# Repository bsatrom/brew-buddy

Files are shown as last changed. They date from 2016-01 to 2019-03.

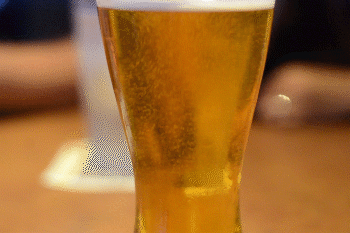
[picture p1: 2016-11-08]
resources/images/bubbles.gif

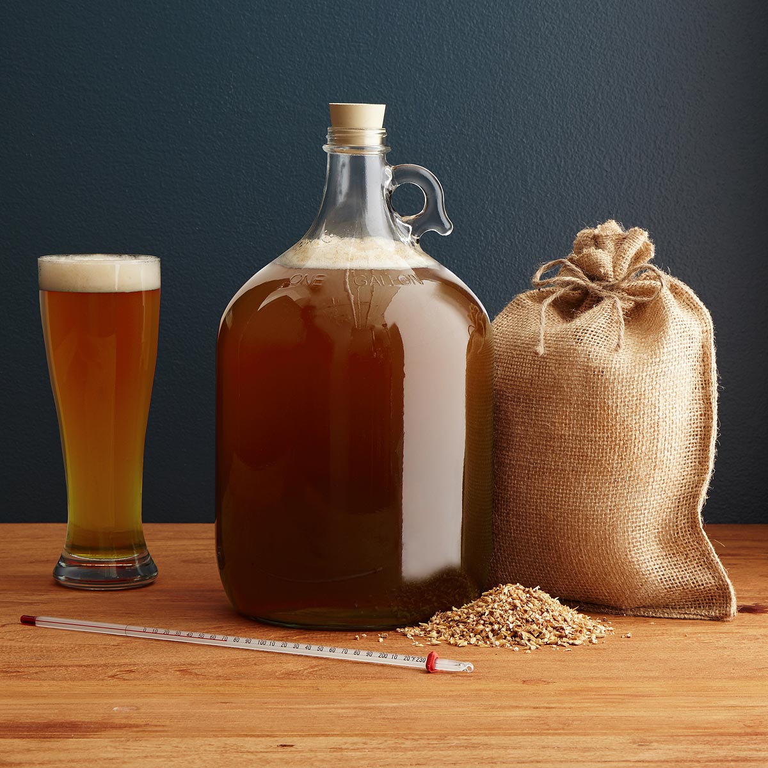
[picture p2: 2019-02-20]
resources/images/homebrew.jpg

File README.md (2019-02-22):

# Brew Buddy

Build Status (https://dev.azure.com/brandon0360/BrewBuddy/_build/latest?definitionId=1&branchName=master)

Source for the BrewBuddy project. Contains sources for board hardware/layout, firmware and a 3d printed enclosure.

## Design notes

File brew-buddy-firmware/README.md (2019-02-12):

# brew-buddy-firmware

A Particle project named brew-buddy-firmware

## Welcome to your project!

Every new Particle project is composed of 3 important elements that you'll see have been created in your project directory for brew-buddy-firmware.

#### ```/src``` folder:  
This is the source folder that contains the firmware files for your project. It should *not* be renamed. 
Anything that is in this folder when you compile your project will be sent to our compile service and compiled into a firmware binary for the Particle device that you have targeted.

If your application contains multiple files, they should all be included in the `src` folder. If your firmware depends on Particle libraries, those dependencies are specified in the `project.properties` file referenced below.

#### ```.ino``` file:
This file is the firmware that will run as the primary application on your Particle device. It contains a `setup()` and `loop()` function, and can be written in Wiring or C/C++. For more information about using the Particle firmware API to create firmware for your Particle device, refer to the [Firmware Reference](https://docs.particle.io/reference/firmware/) section of the Particle documentation.

#### ```project.properties``` file:  
This is the file that specifies the name and version number of the libraries that your project depends on. Dependencies are added automatically to your `project.properties` file when you add a library to a project using the `particle library add` command in the CLI or add a library in the Desktop IDE.

## Adding additional files to your project

#### Projects with multiple sources
If you would like add additional files to your application, they should be added to the `/src` folder. All files in the `/src` folder will be sent to the Particle Cloud to produce a compiled binary.

#### Projects with external libraries
If your project includes a library that has not been registered in the Particle libraries system, you should create a new folder named `/lib/<libraryname>/src` under `/<project dir>` and add the `.h`, `.cpp` & `library.properties` files for your library there. Read the [Firmware Libraries guide](https://docs.particle.io/guide/tools-and-features/libraries/) for more details on how to develop libraries. Note that all contents of the `/lib` folder and subfolders will also be sent to the Cloud for compilation.

## Compiling your project

When you're ready to compile your project, make sure you have the correct Particle device target selected and run `particle compile <platform>` in the CLI or click the Compile button in the Desktop IDE. The following files in your project folder will be sent to the compile service:

- Everything in the `/src` folder, including your `.ino` application file
- The `project.properties` file for your project
- Any libraries stored under `lib/<libraryname>/src`

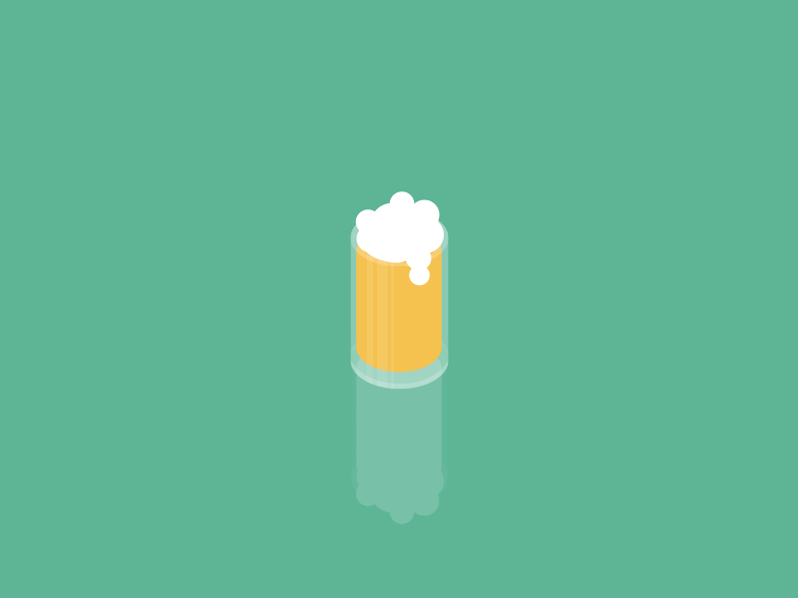
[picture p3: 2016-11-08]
resources/images/animation.gif

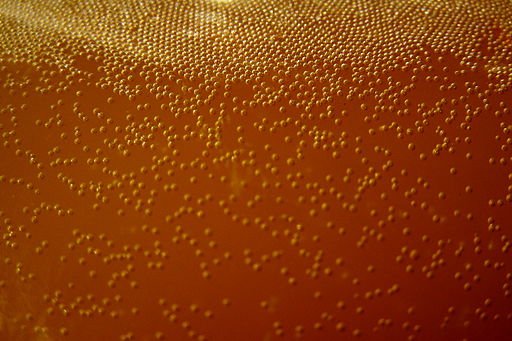
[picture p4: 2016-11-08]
resources/images/bubbles.jpg

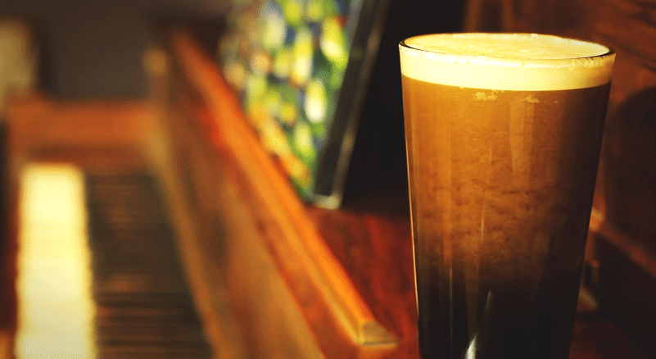
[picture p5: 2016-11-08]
resources/images/goodstuff.gif

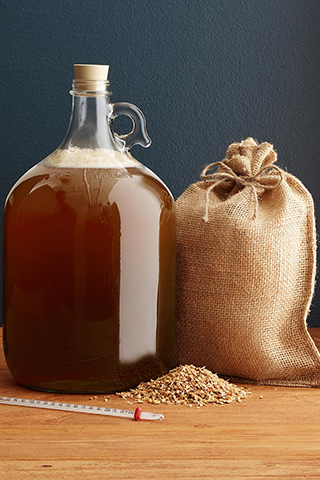
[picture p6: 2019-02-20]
resources/images/brew.bmp

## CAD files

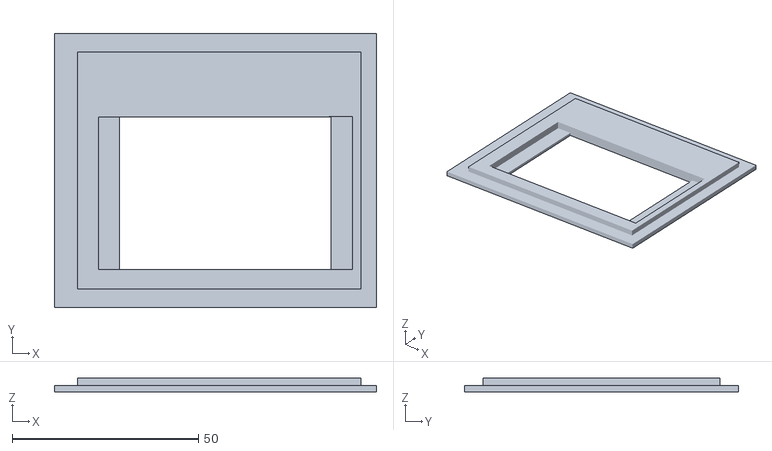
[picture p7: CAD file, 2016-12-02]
brew-buddy-enclosure/enclosure-top.stl
86.5 x 73.5 x 3.72

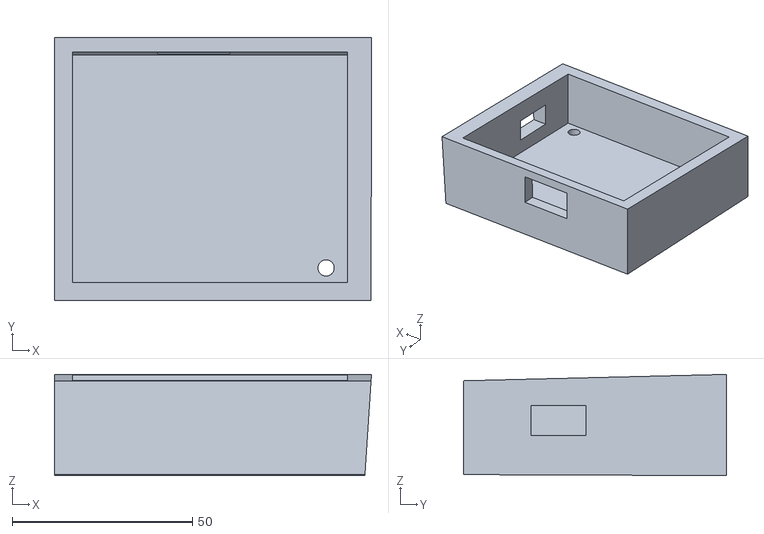
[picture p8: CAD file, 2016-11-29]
brew-buddy-enclosure/enclosure.stl
87.8 x 73.0 x 28.0

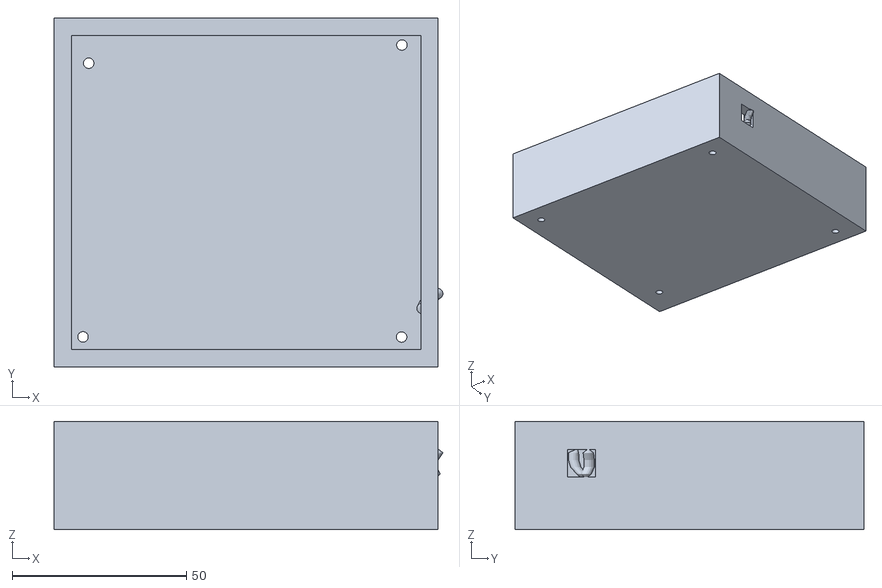
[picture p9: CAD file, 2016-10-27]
brew-buddy-enclosure/enclosure-with-supports.stl
111.5 x 100.0 x 31.0

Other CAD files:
brew-buddy-enclosure/Untitled.stl

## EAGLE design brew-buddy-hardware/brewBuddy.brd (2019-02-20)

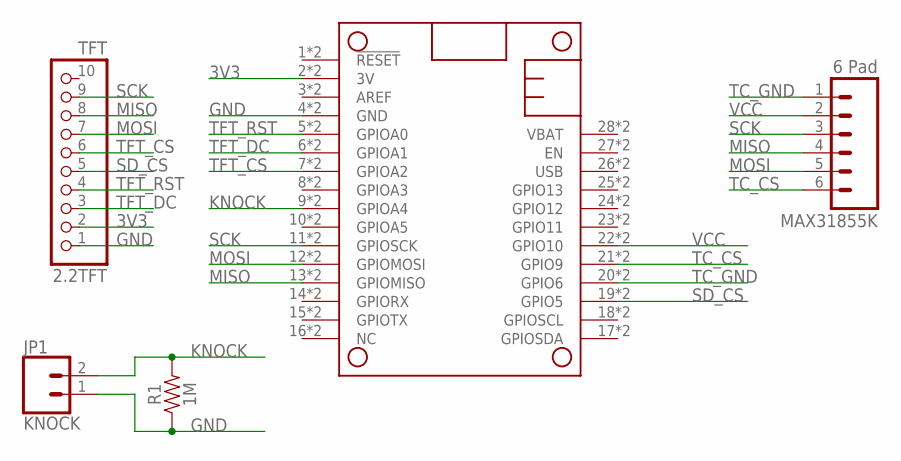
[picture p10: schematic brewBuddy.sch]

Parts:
2.2TFT: TFT; MICROBUILDER_1X10_ROUND_2MM
JP1: KNOCK; SCREWTERMINAL-5MM-2
MAX31855K: 6 Pad; 1X06_LONGPADS
MS1: FEATHERWING_SMTDUAL; FEATHERWING_SMT2
R1: 1M; 0805

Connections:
3V3: 2.2TFT.2, MS1.2 (3V), MS1.2' (3V)
GND: 2.2TFT.1, JP1.1, MS1.4 (GND), MS1.4' (GND), R1.1
KNOCK: JP1.2, MS1.9 (GPIOA4), MS1.9' (GPIOA4), R1.2
MISO: 2.2TFT.8, MAX31855K.4, MS1.13 (GPIOMISO), MS1.13' (GPIOMISO)
MOSI: 2.2TFT.7, MAX31855K.5, MS1.12 (GPIOMOSI), MS1.12' (GPIOMOSI)
SCK: 2.2TFT.9, MAX31855K.3, MS1.11 (GPIOSCK), MS1.11' (GPIOSCK)
SD_CS: 2.2TFT.5, MS1.19 (GPIO5), MS1.19' (GPIO5)
TC_CS: MAX31855K.6, MS1.21 (GPIO9), MS1.21' (GPIO9)
TC_GND: MAX31855K.1, MS1.20 (GPIO6), MS1.20' (GPIO6)
TFT_CS: 2.2TFT.6, MS1.7 (GPIOA2), MS1.7' (GPIOA2)
TFT_DC: 2.2TFT.3, MS1.6 (GPIOA1), MS1.6' (GPIOA1)
TFT_RST: 2.2TFT.4, MS1.5 (GPIOA0), MS1.5' (GPIOA0)
VCC: MAX31855K.2, MS1.22 (GPIO10), MS1.22' (GPIO10)

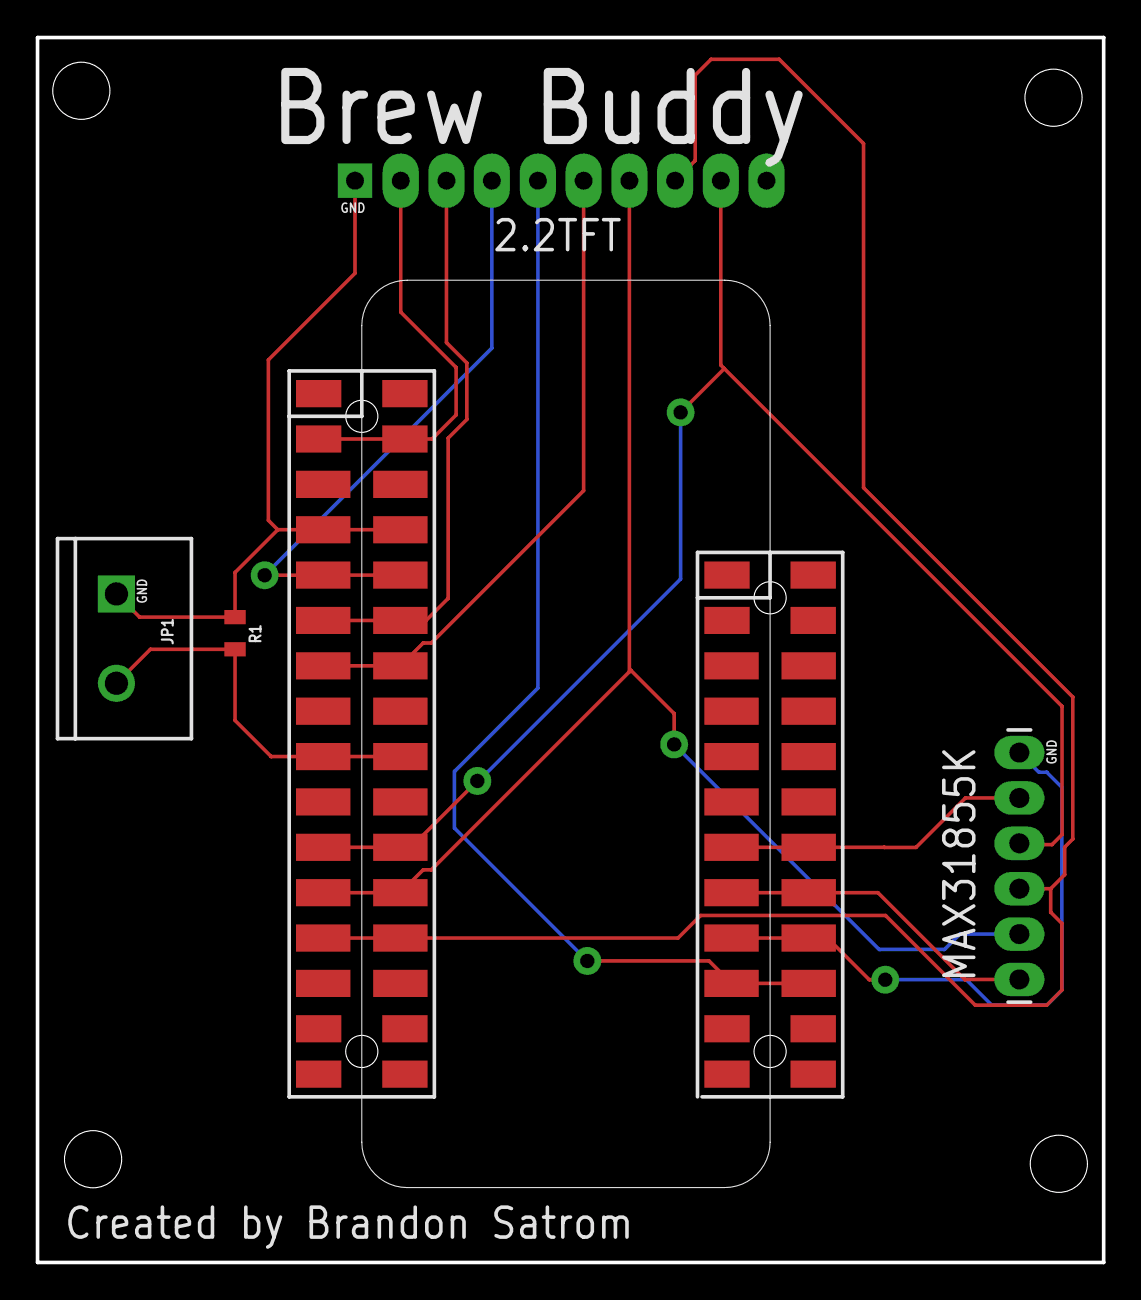
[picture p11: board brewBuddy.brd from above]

Board: 2 copper layers, 59.7 x 68.6 mm, 5 parts (0 on the bottom side), 13 nets.

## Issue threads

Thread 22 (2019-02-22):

Fix temp monitoring posts to Device Cloud

bsatrom, 2019-02-22:

Closed 2019-02-28.

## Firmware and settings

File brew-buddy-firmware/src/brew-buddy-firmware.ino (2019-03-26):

#include "math.h"
#include "QueueArray.h"
#include "beerBitmap.h"

// Thermocouple Includes
#include "SparkFunMAX31855k.h"

// TFT Includes
#include "Adafruit_ILI9341.h"
#include "Adafruit_ImageReader.h"

// Include for SD Card reader on TFT
#include "SdFat.h"

// Include MQTT Library to enable the Azure IoT Hub to call back to our device
#include "MQTT-TLS.h"
#include "certs/certs.h"

// Json parser for working with MQTT responses from Azure IoT Hub
#include "JsonParserGeneratorRK.h"
JsonParserStatic<2048, 100> jsonParser;

// App Version Constant
#define APP_VERSION "v1.0"

SYSTEM_THREAD(ENABLED);

String deviceID;

// Thermocouple Variables
const uint8_t CHIP_SELECT_PIN = D4;
// SCK, MISO & MOSI are defined on Particle 3rd Gen HW at A6-A8
const uint8_t VCC = D5;
const uint8_t GND = D3;
// Instantiate an instance of the SparkFunMAX31855k class
SparkFunMAX31855k probe(CHIP_SELECT_PIN, VCC, GND);

// CS Pin for SD Card on TFT
#define SD_CS D2
#define TFT_CS A2
#define TFT_DC A1
#define TFT_RST A0
// Use hardware SPI
// cs = A2, dc = A1, rst = A0
Adafruit_ILI9341 tft = Adafruit_ILI9341(TFT_CS, TFT_DC, TFT_RST);
Adafruit_ImageReader reader; // Class w/image-reading functions
Adafruit_Image img;          // An image loaded into RAM
int32_t width = 0,           // BMP image dimensions
    height = 0;

#define TFT_SPEED 120000000
#define BATT_LOW_VOLTAGE 30

// SD Card
SdFat sd;

// #include "bmpDraw.h"

// Knock sensor pin
const uint8_t KNOCK_PIN = A4;

// Timing Variables
unsigned long previousTempMillis = 0;
unsigned long tempInterval = 5000;
unsigned long startTime = 0;
unsigned long elapsedTime;
float previousTemp = 0;

// Timing variables for posting readings to the cloud
unsigned long postInterval = 120000;
unsigned long previousPostMillis = 0;

// Timing variables for checking the battery state
unsigned long battInterval = 300000;
unsigned long previousBattMillis = 0;

//Text Size Variables
const uint8_t headingTextSize = 4;
const uint8_t subheadTextSize = 2;
const uint8_t tempTextSize = 5;
const uint8_t elapsedTimeSize = 3;
const uint8_t fermentationRateSize = 5;
const uint8_t pixelMultiplier = 7; //Used to clear text portions of the screen

//QueueArray for the last 22 temperature readings for the TFT Graph
QueueArray<int> tempGraphArray;
const uint8_t lowTemp = 70;
const uint8_t highTemp = 220;
float lastTemp = 0.0;

//Brew Stage Variables
bool isBrewingMode = false;
bool isFermentationMode = false;

//Variables for fermentation detection
bool isFermenting = false;
unsigned long fermentationModeStartTime = 0;
unsigned long fermentationStartTime = 0;

// Variables for fermentation rate
QueueArray<long> knockArray;
float fermentationRate = 0; // knocks per ms
unsigned long lastKnock;
#define KNOCK_INTERVAL 50

String messageBase = "bb/";

String brewStage;
String brewId;

// MQTT Callback fw declaration and client
void mqttCB(char *topic, byte *payload, unsigned int length);
MQTT client("brew-buddy-hub.azure-devices.net", 8883, mqttCB);

void setup()
{
  Serial.begin(9600);
  deviceID = System.deviceID();

  pinMode(KNOCK_PIN, INPUT_PULLDOWN);

  //Particle Variables
  Particle.variable("brewStage", brewStage);
  Particle.variable("brewId", brewId);

  //Brew Stage cloud functions
  Particle.function("setMode", setBrewMode);
  Particle.function("checkTemp", checkTemp);
  Particle.function("checkRate", checkFermentationRate);
  Particle.function("checkBatt", checkBatterylevel);

  // Initialize TFT
  tft.begin(TFT_SPEED);

  Serial.print("Initializing SD card...");
  if (!sd.begin(SD_CS))
  {
    sd.initErrorHalt();
    Serial.println("failed!");
  }
  else
  {
    Serial.println("OK!");
  }

  printSplash();

  tft.fillScreen(ILI9341_BLACK);
  printSubheadingLine("Waiting for Brew...");

  // Check and display the battery level
  int battLevel = getBattPercentage();
  displayBattLevel(battLevel);

  waitUntil(Particle.connected);

  Particle.publish("Version", APP_VERSION);
  Particle.publish("Status", "Brew Buddy Online");

  //Connect to Azure MQTT Server
  client.enableTls(certificates, sizeof(certificates));
  client.connect(deviceID, "brew-buddy-hub.azure-devices.net/" + deviceID, "SharedAccessSignature sr=brew-buddy-hub.azure-devices.net&sig=PQZleYaaxEu5VDlE9NTjKWpN%2FnZdL2MBu%2B0A5Xl2YbM%3D&skn=iothubowner&se=1553642020");
  if (client.isConnected())
  {
    Particle.publish("mqtt/status", "connected");
    bool msgSubResult = client.subscribe("devices/" + deviceID + "/messages/devicebound/#", MQTT::QOS0);

    Particle.publish("mqtt/message-sub-result", msgSubResult ? "subscribed to hub messages" : "subscription failed");
  }
  else
  {
    Particle.publish("mqtt/status", "failed");
  }
}

void loop()
{
  unsigned long currentMillis = millis();

  if (isFermentationMode)
  {
    int16_t knockVal = analogRead(KNOCK_PIN) / 16;

    if (knockVal >= 6)
    {
      Serial.printlnf("Knock Val: %d", knockVal);

      if (!isFermenting)
      {
        isFermenting = true;
        fermentationStartTime = millis();
        lastKnock = fermentationStartTime;

        clearScreen();
        tft.setCursor(0, 30);
        tft.setTextColor(ILI9341_YELLOW);
        tft.setTextSize(2);
        tft.print("Fermentation started");
        tft.setTextColor(ILI9341_WHITE);

        displayFermentationHeading();
        displayFermentationModeDelta();

        waitUntil(Particle.connected);
        Particle.publish(messageBase + "ferment/state", "start");
      }
      else if (millis() - lastKnock > KNOCK_INTERVAL)
      {
        knockArray.push(millis() - lastKnock);
        lastKnock = millis();
        fermentationRate = getFermentationRate() / 1000.00; // # of ms between knocks

        displayFermentationRate(fermentationRate);
      }
    }
  }
  else if (isBrewingMode)
  {
    if (currentMillis - previousTempMillis > tempInterval)
    {
      previousTempMillis = currentMillis;

      float temp = readTemp();

      // Don't update the display if the temp hasn't changed
      if (temp != previousTemp)
      {

        if (temp != 0)
        {
          previousTemp = temp;
        }
        printReading(previousTemp);
      }

      if (temp != 0)
      {
        updateChart(temp);
      }
    }

    if ((currentMillis % 1000L) == 0)
    {
      elapsedTime = currentMillis - startTime;

      displayTime(elapsedTime);
    }
  }

  if (currentMillis - previousBattMillis > battInterval)
  {
    previousBattMillis = millis();

    int battLevel = getBattPercentage();

    displayBattLevel(battLevel);
    Particle.publish(messageBase + "batt-level", String(battLevel));

    if (battLevel < BATT_LOW_VOLTAGE)
    {
      displayLowBattAlert();
      Particle.publish(messageBase + "alert", "low-batt");
    }
  }

  if (currentMillis - previousPostMillis > postInterval)
  {
    previousPostMillis = millis();

    if (isBrewingMode)
    {
      postTemp(lastTemp);
    }
    else if (isFermentationMode)
    {
      postFermentationRate();
    }

    postSensorData();
  }

  if (client.isConnected())
  {
    client.loop();
  }
}

void resetFermentationVariables()
{
  isFermenting = false;
  fermentationModeStartTime = 0;
  fermentationStartTime = 0;
  fermentationRate = 0;
}

long getFermentationRate()
{
  long rate = 0.0;
  uint16_t arrayCount = knockArray.count();
  uint16_t sum = 0;

  for (int i = 0; i < arrayCount; i++)
  {
    uint16_t currentVal = knockArray.dequeue();
    sum += currentVal;
    knockArray.enqueue(currentVal);
  }

  rate = sum / arrayCount;

  return rate;
}

int checkBatterylevel(String args)
{
  int battLevel = getBattPercentage();
  Particle.publish(messageBase + "batt-level", String(battLevel));

  return 1;
}

int checkFermentationRate(String args)
{
  if (isFermentationMode)
  {
    postFermentationRate();

    return 1;
  }

  return 0;
}

int checkTemp(String args)
{
  if (isBrewingMode)
  {
    float temp = readTemp();
    postTemp(temp);

    return 1;
  }

  return 0;
}

int getBattPercentage()
{
  int voltage = analogRead(BATT) * 0.0011224;

  return (int)((voltage / 4.2) * 100 + 0.5);
}

void activateBrewStage()
{
  startTime = millis();

  displayTempHeading();
  displayTempHistoryHeading();
  displayTimeHeading();
}

int setBrewMode(String command)
{
  String commands[3];
  int counter = 0;
  char buffer[63]; //63 characters is the max length of the Particle string

  command.toCharArray(buffer, 63);

  char *cmd = strtok(buffer, ",");
  while (cmd != 0)
  {
    commands[counter] = cmd;
    counter++;

    cmd = strtok(NULL, ",");
  }
  free(cmd);

  brewStage = commands[2];
  brewId = commands[1];

  if (commands[0] == "brew" && !isBrewingMode)
  {
    isBrewingMode = true;
    isFermentationMode = false;

    clearScreen();
    activateBrewStage();

    return 1;
  }
  else if (commands[0] == "ferment")
  {
    isBrewingMode = false;
    isFermentationMode = true;
    fermentationModeStartTime = millis();

    clearScreen();
    tft.setCursor(0, 140);
    printSubheadingLine("Waiting for");
    printSubheadingLine("Fermentation...");

    System.sleep(KNOCK_PIN, CHANGE);

    return 1;
  }
  else if (commands[0] == "stop")
  {
    isBrewingMode = false;
    isFermentationMode = false;
    resetFermentationVariables();

    clearScreen();
    tft.setCursor(0, 140);
    printSubheadingLine("Waiting for Brew...");

    return 1;
  }

  return 0;
}

void printSplash()
{
  ImageReturnCode stat;
  tft.setRotation(2);

  clearScreen();

  Serial.println("Loading brew.bmp to screen...");
  stat = reader.drawBMP("brew.bmp", tft, sd, 0, 0);
  reader.printStatus(stat); // How'd we do?

  delay(2000);

  tft.setCursor(0, 40);
  printHeadingTextLine("BrewBuddy");
  printHeadingTextLine(APP_VERSION);
  printSubheadingLine("Created by");
  printSubheadingLine("Brandon Satrom");
  delay(3000);
}

void clearTopBar()
{
  tft.fillRect(0, 0, 240, 30, ILI9341_BLACK);
  tft.setCursor(0, 0);
  tft.setTextColor(ILI9341_WHITE);
}

void clearScreen()
{
  tft.fillRect(0, 30, 240, 320, ILI9341_BLACK);
  tft.setCursor(0, 0);
  tft.setTextColor(ILI9341_WHITE);
}

void printHeadingTextLine(String text)
{
  tft.setTextSize(headingTextSize);
  tft.println(text);
}

void printSubheadingLine(String text)
{
  tft.setTextSize(subheadTextSize);
  tft.println(text);
}

float readTemp()
{
  float temperature = probe.readTempF();

  if (!isnan(temperature))
  {
    lastTemp = temperature;

    return temperature;
  }
  else
  {
    Serial.println("Could not read temp");
    return 0;
  }
}

void postSensorData()
{
  JsonWriterStatic<256> jsonWriter;

  {
    JsonWriterAutoObject obj(&jsonWriter);

    jsonWriter.insertKeyValue("temperature", lastTemp);
    jsonWriter.insertKeyValue("fermentation-rate", fermentationRate);
    jsonWriter.insertKeyValue("battery-charge", String(getBattPercentage()));
  }

  Particle.publish(messageBase + "latest", jsonWriter.getBuffer());
}

void postTemp(float temp)
{
  Particle.publish(messageBase + "brew/temp", String(temp, 2));
}

void postFermentationRate()
{
  Particle.publish(messageBase + "ferment/rate", String(fermentationRate, 2));
}

void printReading(float reading)
{
  tft.fillRect(0, 60, 240, tempTextSize * pixelMultiplier, ILI9341_BLACK);
  tft.setCursor(0, 60);

  if (reading <= 80)
  {
    tft.setTextColor(ILI9341_BLUE);
  }
  else if (reading > 80 && reading <= 110)
  {
    tft.setTextColor(ILI9341_YELLOW);
  }
  else if (reading > 110)
  {
    tft.setTextColor(ILI9341_RED);
  }

  tft.setTextSize(tempTextSize);
  tft.println(reading);

  tft.setTextColor(ILI9341_WHITE);
}

void displayStageName(String stagename)
{
  tft.setCursor(0, 10);
  tft.setTextColor(ILI9341_YELLOW);
  tft.setTextSize(2);
  tft.print("Stage: ");
  tft.println(stagename);
  tft.setTextColor(ILI9341_WHITE);
}

void displayFermentationHeading()
{
  tft.setCursor(0, 110);
  tft.setTextSize(2);
  tft.println("Fermentation Rate");
  tft.println("(in seconds)");
}

void displayFermentationModeDelta()
{
  unsigned long fermentationDelta = fermentationStartTime - fermentationModeStartTime;

  tft.setCursor(0, 60);
  tft.setTextSize(2);
  tft.println("Time to fermentation (hours)");
  tft.println(fermentationDelta / 36000000.00);
}

void displayTimeHeading()
{
  tft.setCursor(0, 120);
  tft.setTextSize(2);
  tft.println("Elapsed Time");
}

void displayTempHeading()
{
  tft.setCursor(0, 40);
  tft.setTextSize(2);
  tft.println("Wort Temp (F)");
}

void displayTempHistoryHeading()
{
  tft.setCursor(0, 170);
  tft.setTextSize(2);
  tft.println("Temp History");
}

void displayFermentationRate(long rate)
{
  tft.fillRect(0, 150, 240, fermentationRateSize * pixelMultiplier, ILI9341_BLACK);
  tft.setCursor(0, 150);
  tft.setTextSize(fermentationRateSize);
  tft.println(rate);
}

void displayTime(float elapsedTime)
{
  String timeString = calcTimeToDisplay(elapsedTime);

  tft.fillRect(0, 140, 240, elapsedTimeSize * pixelMultiplier, ILI9341_BLACK);
  tft.setCursor(0, 140);
  tft.setTextSize(elapsedTimeSize);
  tft.println(timeString);
}

void displayBattLevel(int voltage)
{
  clearTopBar();
  tft.setCursor(160, 10);
  tft.setTextSize(1);
  tft.print("Batt: ");
  tft.print(voltage);
  tft.println("%");
}

void displayLowBattAlert()
{
  tft.setCursor(10, 10);
  tft.setTextSize(2);
  tft.setTextColor(ILI9341_RED);
  tft.println("LOW BATT");
  tft.setTextColor(ILI9341_WHITE);
}

String calcTimeToDisplay(float elapsedTime)
{
  String padZero = "0";
  String timeString;

  int timeInSec = (int)(elapsedTime / 1000L);
  int timeInMin = timeInSec / 60;
  int timeRemainder = timeInSec % 60;

  if (timeInMin < 10)
  {
    timeString = padZero;
  }
  timeString += String(timeInMin) + ":";

  if (timeRemainder < 10)
  {
    timeString += padZero;
  }
  timeString += timeRemainder;

  return timeString;
}

void updateChart(float temp)
{
  int yLocation;
  int yDiff;
  int roundedTemp = (int)temp;
  int arrayLength = 0;

  if (roundedTemp < lowTemp)
  {
    yLocation = 315;
  }
  else if (roundedTemp > highTemp)
  {
    yLocation = 220;
  }
  else
  {
    yDiff = roundedTemp - lowTemp;

    yLocation = 320 - yDiff;
  }

  if (tempGraphArray.count() == 22)
  {
    tempGraphArray.dequeue();
  }
  tempGraphArray.enqueue(yLocation);

  tft.fillRect(0, 190, 240, 150, ILI9341_BLACK);

  //Iterate on the QueueArray for displaying on the screen
  if (tempGraphArray.count() > 22)
  {
    arrayLength = 22;
  }
  else
  {
    arrayLength = tempGraphArray.count();
  }

  for (int i = 0; i < arrayLength; i++)
  {
    int currentLocation = tempGraphArray.dequeue();

    tft.fillCircle(10 * (i + 1), currentLocation, 4, ILI9341_RED);

    //Queue the front value back onto the end of the array
    tempGraphArray.enqueue(currentLocation);
  }
}

void mqttCB(char *topic, byte *payload, unsigned int length)
{
  char pload[length + 1];
  memcpy(pload, payload, length);
  pload[length] = NULL;

  Serial.printlnf("Topic: %s", topic);
  Serial.printlnf("Payload: %s", pload);

  jsonParser.clear();
  jsonParser.addString(pload);

  if (jsonParser.parse())
  {
    String methodName = jsonParser.getReference().key("methodName").valueString();

    Particle.publish("mqtt/message-method", methodName);

    setBrewMode(methodName);
  }
}

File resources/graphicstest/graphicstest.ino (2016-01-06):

/***************************************************
  This is an example sketch for the Adafruit 2.2" SPI display.
  This library works with the Adafruit 2.2" TFT Breakout w/SD card
  ----> http://www.adafruit.com/products/1480
 
  Check out the links above for our tutorials and wiring diagrams
  These displays use SPI to communicate, 4 or 5 pins are required to
  interface (RST is optional)
  Adafruit invests time and resources providing this open source code,
  please support Adafruit and open-source hardware by purchasing
  products from Adafruit!

  Written by Limor Fried/Ladyada for Adafruit Industries.
  MIT license, all text above must be included in any redistribution
 ****************************************************/
 
#include "SPI.h"
#include "Adafruit_GFX.h"
#include "Adafruit_ILI9340.h"

#if defined(__SAM3X8E__)
    #undef __FlashStringHelper::F(string_literal)
    #define F(string_literal) string_literal
#endif

// These are the pins used for the UNO
// for Due/Mega/Leonardo use the hardware SPI pins (which are different)
#define _sclk 13
#define _miso 12
#define _mosi 11
#define _cs 7 // Changed from original 
#define _dc 9
#define _rst 8

// Using software SPI is really not suggested, its incredibly slow
//Adafruit_ILI9340 tft = Adafruit_ILI9340(_cs, _dc, _mosi, _sclk, _rst, _miso);
// Use hardware SPI
Adafruit_ILI9340 tft = Adafruit_ILI9340(_cs, _dc, _rst);

void setup() {
  Serial.begin(9600);
  while (!Serial);
  
  Serial.println("Adafruit 2.2\" SPI TFT Test!"); 
 
  tft.begin();

  Serial.println(F("Benchmark                Time (microseconds)"));
  Serial.print(F("Screen fill              "));
  Serial.println(testFillScreen());
  delay(500);

  Serial.print(F("Text                     "));
  Serial.println(testText());
  delay(3000);

  Serial.print(F("Lines                    "));
  Serial.println(testLines(ILI9340_CYAN));
  delay(500);

  Serial.print(F("Horiz/Vert Lines         "));
  Serial.println(testFastLines(ILI9340_RED, ILI9340_BLUE));
  delay(500);

  Serial.print(F("Rectangles (outline)     "));
  Serial.println(testRects(ILI9340_GREEN));
  delay(500);

  Serial.print(F("Rectangles (filled)      "));
  Serial.println(testFilledRects(ILI9340_YELLOW, ILI9340_MAGENTA));
  delay(500);

  Serial.print(F("Circles (filled)         "));
  Serial.println(testFilledCircles(10, ILI9340_MAGENTA));

  Serial.print(F("Circles (outline)        "));
  Serial.println(testCircles(10, ILI9340_WHITE));
  delay(500);

  Serial.print(F("Triangles (outline)      "));
  Serial.println(testTriangles());
  delay(500);

  Serial.print(F("Triangles (filled)       "));
  Serial.println(testFilledTriangles());
  delay(500);

  Serial.print(F("Rounded rects (outline)  "));
  Serial.println(testRoundRects());
  delay(500);

  Serial.print(F("Rounded rects (filled)   "));
  Serial.println(testFilledRoundRects());
  delay(500);

  Serial.println(F("Done!"));
}

void loop(void) {
  for(uint8_t rotation=0; rotation<4; rotation++) {
    tft.setRotation(rotation);
    testText();
    delay(2000);
  }
}


unsigned long testFillScreen() {
  unsigned long start = micros();
  tft.fillScreen(ILI9340_BLACK);
  tft.fillScreen(ILI9340_RED);
  tft.fillScreen(ILI9340_GREEN);
  tft.fillScreen(ILI9340_BLUE);
  tft.fillScreen(ILI9340_BLACK);
  return micros() - start;
}

unsigned long testText() {
  tft.fillScreen(ILI9340_BLACK);
  unsigned long start = micros();
  tft.setCursor(0, 0);
  tft.setTextColor(ILI9340_WHITE);  tft.setTextSize(1);
  tft.println("Hello World!");
  tft.setTextColor(ILI9340_YELLOW); tft.setTextSize(2);
  tft.println(1234.56);
  tft.setTextColor(ILI9340_RED);    tft.setTextSize(3);
  tft.println(0xDEADBEEF, HEX);
  tft.println();
  tft.setTextColor(ILI9340_GREEN);
  tft.setTextSize(5);
  tft.println("Groop");
  tft.setTextSize(2);
  tft.println("I implore thee,");
  tft.setTextSize(1);
  tft.println("my foonting turlingdromes.");
  tft.println("And hooptiously drangle me");
  tft.println("with crinkly bindlewurdles,");
  tft.println("Or I will rend thee");
  tft.println("in the gobberwarts");
  tft.println("with my blurglecruncheon,");
  tft.println("see if I don't!");
  return micros() - start;
}

unsigned long testLines(uint16_t color) {
  unsigned long start, t;
  int           x1, y1, x2, y2,
                w = tft.width(),
                h = tft.height();

  tft.fillScreen(ILI9340_BLACK);

  x1 = y1 = 0;
  y2    = h - 1;
  start = micros();
  for(x2=0; x2<w; x2+=6) tft.drawLine(x1, y1, x2, y2, color);
  x2    = w - 1;
  for(y2=0; y2<h; y2+=6) tft.drawLine(x1, y1, x2, y2, color);
  t     = micros() - start; // fillScreen doesn't count against timing

  tft.fillScreen(ILI9340_BLACK);

  x1    = w - 1;
  y1    = 0;
  y2    = h - 1;
  start = micros();
  for(x2=0; x2<w; x2+=6) tft.drawLine(x1, y1, x2, y2, color);
  x2    = 0;
  for(y2=0; y2<h; y2+=6) tft.drawLine(x1, y1, x2, y2, color);
  t    += micros() - start;

  tft.fillScreen(ILI9340_BLACK);

  x1    = 0;
  y1    = h - 1;
  y2    = 0;
  start = micros();
  for(x2=0; x2<w; x2+=6) tft.drawLine(x1, y1, x2, y2, color);
  x2    = w - 1;
  for(y2=0; y2<h; y2+=6) tft.drawLine(x1, y1, x2, y2, color);
  t    += micros() - start;

  tft.fillScreen(ILI9340_BLACK);

  x1    = w - 1;
  y1    = h - 1;
  y2    = 0;
  start = micros();
  for(x2=0; x2<w; x2+=6) tft.drawLine(x1, y1, x2, y2, color);
  x2    = 0;
  for(y2=0; y2<h; y2+=6) tft.drawLine(x1, y1, x2, y2, color);

  return micros() - start;
}

unsigned long testFastLines(uint16_t color1, uint16_t color2) {
  unsigned long start;
  int           x, y, w = tft.width(), h = tft.height();

  tft.fillScreen(ILI9340_BLACK);
  start = micros();
  for(y=0; y<h; y+=5) tft.drawFastHLine(0, y, w, color1);
  for(x=0; x<w; x+=5) tft.drawFastVLine(x, 0, h, color2);

  return micros() - start;
}

unsigned long testRects(uint16_t color) {
  unsigned long start;
  int           n, i, i2,
                cx = tft.width()  / 2,
                cy = tft.height() / 2;

  tft.fillScreen(ILI9340_BLACK);
  n     = min(tft.width(), tft.height());
  start = micros();
  for(i=2; i<n; i+=6) {
    i2 = i / 2;
    tft.drawRect(cx-i2, cy-i2, i, i, color);
  }

  return micros() - start;
}

unsigned long testFilledRects(uint16_t color1, uint16_t color2) {
  unsigned long start, t = 0;
  int           n, i, i2,
                cx = tft.width()  / 2 - 1,
                cy = tft.height() / 2 - 1;

  tft.fillScreen(ILI9340_BLACK);
  n = min(tft.width(), tft.height());
  for(i=n; i>0; i-=6) {
    i2    = i / 2;
    start = micros();
    tft.fillRect(cx-i2, cy-i2, i, i, color1);
    t    += micros() - start;
    // Outlines are not included in timing results
    tft.drawRect(cx-i2, cy-i2, i, i, color2);
  }

  return t;
}
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

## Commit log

2016-01-06 removed Arduino example/test code
2016-01-21 added Eagle files for brew-buddy PCB
    [brewBuddy.brd, brewBuddy.sch]
2016-03-17 added Eagle files
    [brewBuddy.brd]
2016-07-14 widened wires for cnc millin
    [brewBuddy.brd]
2016-07-18 updated brd for othermill
    [brewBuddy.brd]
2016-07-20 moved traces to bottom layer for othermill
    [brewBuddy.brd]
2016-07-20 added BB name to board
    [brewBuddy.brd]
2016-09-06 modified BRD to make room for components
    [brewBuddy.brd]
2016-09-07 additional BRD mods
    [brewBuddy.brd]
2016-10-27 added enclosure files
    [brewBuddy.brd, enclosure.stl]
2016-10-27 added supports
    [enclosure-with-supports.stl]
2016-10-27 updated snclosure with tweaks
    [enclosure.stl]
2016-10-30 tweaked enclosure (v3)
    [enclosure.stl]
2016-10-30 additional enclosure tweaks (v4)
    [enclosure.stl]
2016-10-31 designed top of enclosure
    [enclosure-top.stl]
2016-10-31 tweaked top enclosure
    [enclosure-top.stl]
2016-11-08 modified sketch to show image on startup; tweaked pcb
    [brewBuddy.brd, brewBuddy.sch]
2016-11-29 updated enclosure design for smaller case
2016-11-29 added enclosure STL
    [enclosure.stl]
2016-11-30 modified top of enclosure design
    [enclosure-top.stl]
2019-02-12 re-org and cleanup repo for 2.0 project
    [Untitled.stl, brewBuddy.brd, brewBuddy.sch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]
2019-02-12 change pin mappings for Argon; closes #2; closes #3
2019-02-20 updated schematic and board for Argon
    [brewBuddy.brd, brewBuddy.sch]
2019-02-21 up SPI TFT frequency to 120 MHz; closes #11
2019-02-21 implement System threading; closes #17
2019-02-21 calibrate knock sensor; closes #7
2019-02-22 implemented sleep mode with Knock sensor; closes #10
2019-03-13 Add voltage check function and clean up top bar clearing; closes #41
2019-03-25 implemented filter on fermentation knock detection; closes #36
2019-03-26 fix mqtt message text
    [brew-buddy-firmware.ino]

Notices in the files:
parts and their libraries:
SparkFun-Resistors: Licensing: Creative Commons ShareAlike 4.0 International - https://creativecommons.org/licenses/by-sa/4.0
